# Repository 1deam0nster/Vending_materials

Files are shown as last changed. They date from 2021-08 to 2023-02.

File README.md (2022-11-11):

# !Almavending repo
> Репозиторий для сохранения информации, кода, моделей, и прочего :space_invader:

## 📖 Оглавление

- Структура папок
- Список модулей
- Установка ПО
- Список багов
- Список полезных ссылок
- Релизы
- Лицензия

## 📁 Структура папок

### ПО Вендинг сбер

| Name | Description |
| --- | --- |

| [`Commands`](https://github.com/nhn/tui.editor/tree/master/apps/editor) | Заготовка под Shell script для автоматизации |

### Arduino
Старые версии кода для разных контроллеров и разных машин с разными механиками, надо разобраться, чтот удалить

| Name | Description |
| --- | --- |
| New firmware arduino | [Возможно тут](https://reactjs.org/) будет ссылка на отдельный репозиторий |
| libraries | Папка с библиотеками для компиляции кода |
| Old code | Старые версии кода |
| PlatformIO project | Заготовка прошивки MK под Platformio, не компилируеться из-за новой версии GCC которая указыает на ошибку стандартной библиотеке Servo.h |

### Backup

| Name | Description |
| --- | --- |
| [old.zip | Старые бекапы с большим кол-вом файлов и вложенности(то что не синхронит GIT) + что-то еще |
| [Python_dev_old.zip | Одна их первых версий ПО для Raspberry Pi, простой Flask, роутинг, взаимодействие с MK посредством UART  |
| [Python_dev.zip | Актуальная версия Python app, с мини БД на JSON, интеграция с AQSI, [ссылка](https://github.com/1deam0nster/Python_dev) на отдельный актуальный репозиторий  |
| [`App PAX D200 Sber`](https://github.com/nhn/tui.editor/tree/master/apps/editor) | ПО для терминала Pax D200 для LINUX, ARM |
| [Control Panel Node | Веб приложения на Express Node для управления MK посредством Serial, так и не пригодилось(( |
| [app.py | Старое приложение на Python |
| [app_backup_code | Старое приложение на Python |
| [RPI4_image_alfa | Копия флешки для RPI4 |

### 3D Print Models

| Name | Description |
| --- | --- |
| [Cura | Проекты в куре |
| [Fusion Models | Исходники 3д моделей  |
| [G-Code | Файлы для 3д принтера  |

### Img

Коллекция сохраненок для разных модулей, датчиков, информация по распиновкам. Раздел в процессе наполнения...
<!-- ALL-CONTRIBUTORS-LIST:START - Do not remove or modify this section -->
<!-- prettier-ignore-start -->
<!-- markdownlint-disable -->
<table>
  <tr>
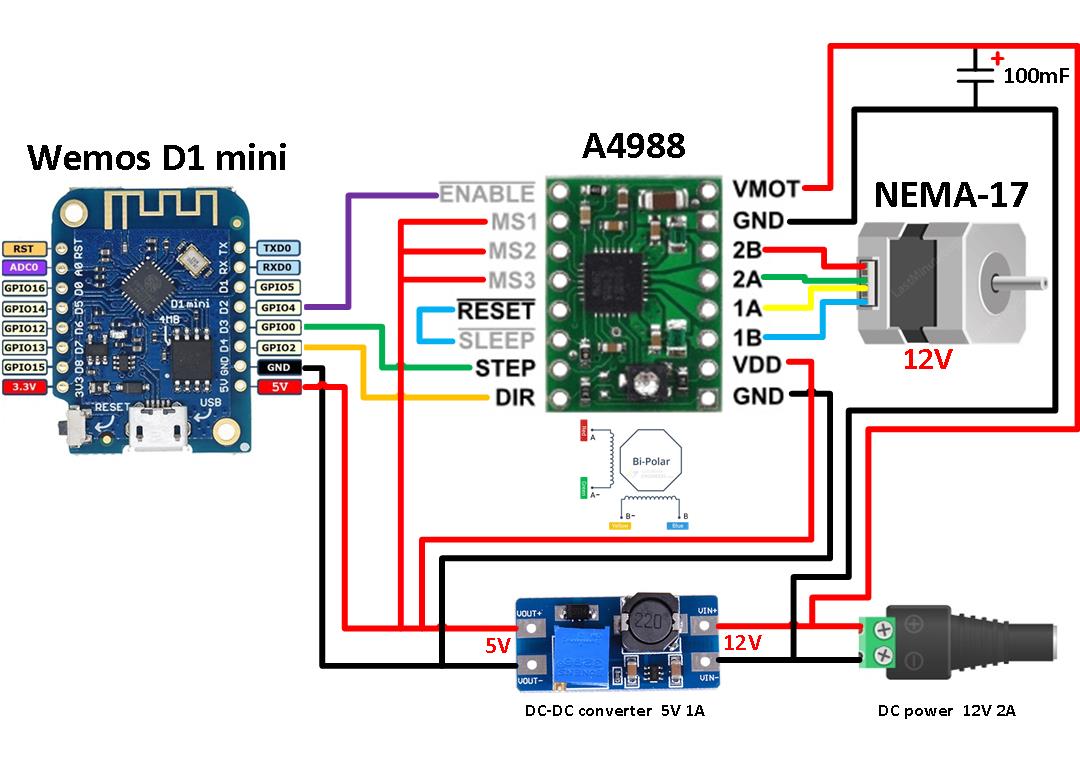
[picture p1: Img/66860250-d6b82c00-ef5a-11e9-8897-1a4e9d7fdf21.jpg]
    <td align="center"></td>
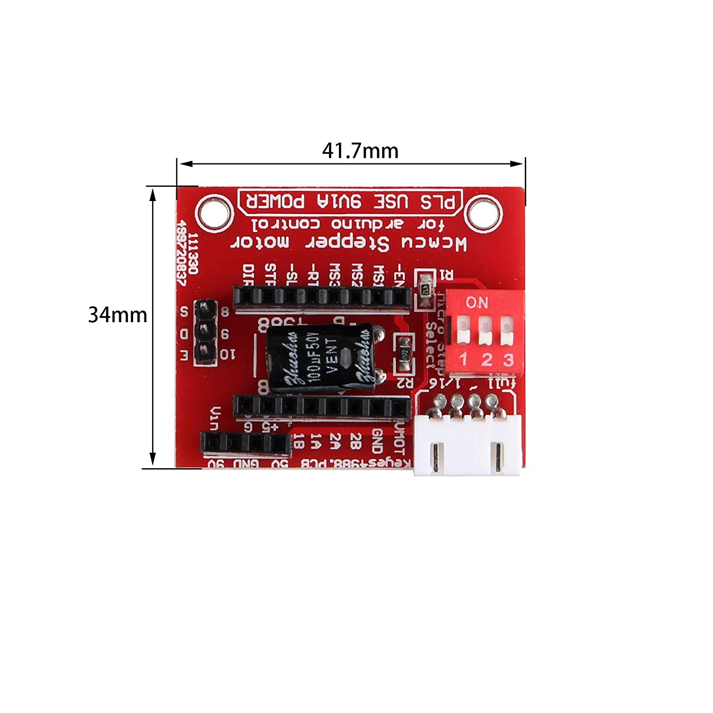
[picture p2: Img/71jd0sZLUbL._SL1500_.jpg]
    <td align="center"></td>
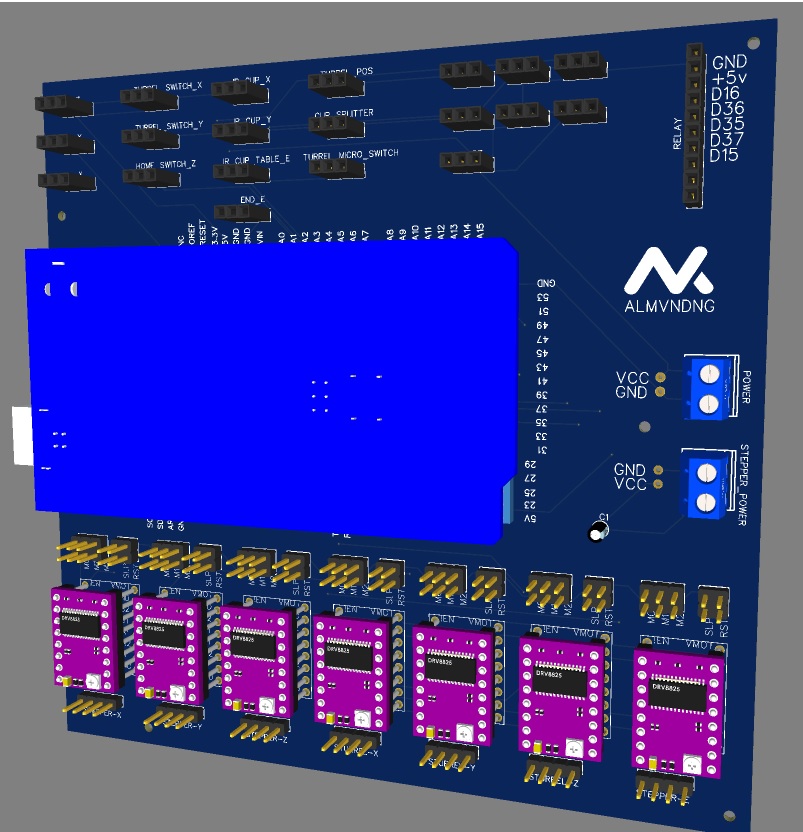
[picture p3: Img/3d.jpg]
    <td align="center"></td>
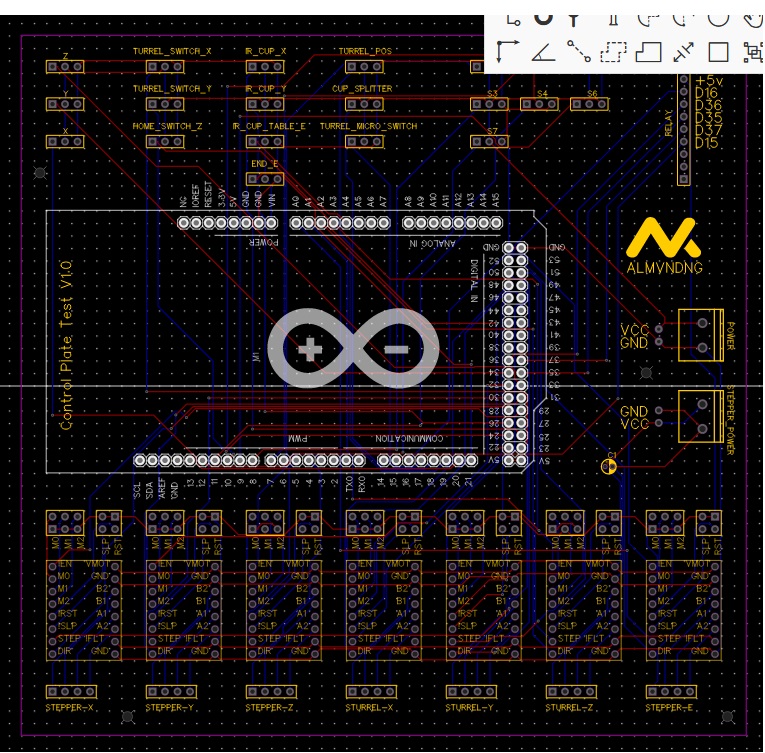
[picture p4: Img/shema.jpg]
    <td align="center"></td>
    <td align="center"></td>
    <td align="center"></td>
    <td align="center"></td>
  </tr>
</table>

<!-- markdownlint-enable -->
<!-- prettier-ignore-end -->
<!-- ALL-CONTRIBUTORS-LIST:END -->

### PCB
Экспорт проекта с ['EasyEDA']:(https://www.easyeda.com) 

##How to recover online project backup：
1、Via folder "online_projects_backup" find out the project as you want
2、Copy to desktop
3、Open the EasyEDA editor, via: Top meun - Open - EasyEDA
4、Select the 'sch' and 'pcb' folder's 'json' files to open, and then save to a new project
5、Saved and finish

### 📃 Python

| Name | Description |
| --- | --- |
| [`evotor`](https://github.com/1deam0nster/Vending_materials/tree/main/Python/Evotor) | Скрипт для отправки фискольных данных в Эвотор |
| [`bot.py`](https://github.com/1deam0nster/Vending_materials/blob/main/Python/bot.py) | Telegram bot для управления машиной |
| [`Aqsi`](https://github.com/1deam0nster/Vending_materials/blob/main/Python/Aqsi) | Aqsi код для фискализации, чека, оплаты |
| [`Python_dev`](https://github.com/1deam0nster/Vending_materials/blob/main/Python/Python_dev) | Основной код для Raspberry PI |

## 🔧 Список модулей на каждую часть

**Турель выдачи стаканчиков**
- Кнопки на input с подтягивающим резистором
- Кнопки на input с подтягивающим резистором
- Кнопки на input с подтягивающим резистором

**Турель с капсулами + кофемашина**
- Магнит для вкл/выкл(Реле)
- Сенсор на землю(Реле) для переключения программы
- Сервопривод
- Сервопривод
- Концевик
- Концевик(в целом резерв)
- Шаговый двигатель(+ драйвер)
- Ir датчик присутствия капсулы
- Механический(оптический) концевик для фиксации завершения приготовления 

**Выдача сливок**
- Шаговый двигатель(+ драйвер)
- Сервопривод
- Сервопривод
- Концевик
- Ir датчик присутствия капсулы

**Выдача сахара**
- Один сервопривод
- Ir датчик присутствия 

**Выдача шоколада**
- Сервопривод
- Ir датчик присутствия 

**Окно**
- Шаговый двигатель
- Концевик
- Датчик расстояния (тот желтый цилиндр, чтобы понять, что стакан забрали)
- Сервопривод (резерв)

**Манипулятор для подачи стакана**
- Шаговый двигатель
- Концевик
- Датчик ИК
- Сервопривод
- Сервопривод

## Установка ПО

Описание в процессе...

```sh
$ git clone https://github.com/{your-personal-repo}/tui.editor.git
$ npm install
$ npm run build toastmark
$ npm run test editor
```
## 🐛Список багов
- [ ] ...

### Примерный список задач

```
### Общие задачи
- [x] Собрать тестовый стенд для кофемашины
- [x] Разработка ПО для микроконтроллера(для тестового стенда), выполнение полного цикла приготовления кофе на тестовом стенде в ручную с компа посредством ручного ввода 
- [x] Разработка Flask приложения(для тестового стенда), выполнение полного цикла приготовления кофе, оплаты, загрузки, ребута, частично реализовать систему обслуживания
- [ ] Разработка платы PCB
- [ ] Собрать полную статистику сколько и каких всего материалов использованно для создания одной кофе машины, создать тут раздел
- [x] Админ панель(обслуживание) или может пока обойтись кнопкой
- [ ] Выход в сеть, легкий удаленный доступ, объединение в одну сеть(хз проще всего наверное VPN)

### Разработка Flask приложения 
- [x] Создание мини БД для учета(почти готово, надо сделать сохранение после перезапуска)
- [x] Роутинг страниц
- [x] Шаблоны для отображения(черновые, пока без дизайна)
- [x] Подумать как будет храниться информация в БД, пока это только объект внутри программы, возможно можно сделать тупо хранение на флешке файлов JSON
- [x] Код для передачи g-code комманд MK 
- [x] Дизайн всех страниц, сверстать, сделать шаблоны 
- [x] Отрефакторить предыдущие наработки, чтоб все было модульно и круто
- [x] Добавить описание как это все запускать, добавить описание к ['репозиторию']:(https://github.com/1deam0nster/Python_dev) Python_dev
- [x] Создать админ панель(обслуживание автомата для начала), отображение статистики продаж

### Разработка ПО для микроконтроллера
- [x] Прописать тестовые команды для отладки
- [ ] Продумать сколько команд нужно для приготовления кофе, разделить их на маленькие части для переиспользования кода, собрать основные команды 
- [X] Обратная связь с Raspberry PI
- [ ] Инициализация eeprom памяти для экстренных ситуаций(когда свет потух, знать местоположение турели, например)
- [ ] Режим обслуживания, сброс кол-ва капсул в ПЗУ(eeprom)
- [ ] Создать репозиторий для кода МК, а то заебало плодить кучу версий 

## Список не глобальных задач
- [x] Создать описание к данному репозиторию
- [ ] отрефакторить размещение и нэйминг
- [ ] Добавить ссылки на остальные репозитории в данный README
- [ ] Добавить папку 3d, разделить её на настройки принтера, 3д модели(Fusion360), g-code
- [ ] Добавить раздел список оборудования и конструкционных материалов(наполнить по окончанию стройки машины, если это возможно)
- [ ] Добавить к списку модулей таблицу с пинами для подключения
- [ ] Собрать все медия материалы для истории
```

## Список полезных ссылок
['Модель дисплея']:(https://www.waveshare.com/product/raspberry-pi/displays/lcd-oled/13.3inch-hdmi-lcd-h.htm)

## Список релизов

* 0.2.1
    * CHANGE: Update docs (module code remains unchanged)
* 0.2.0
    * CHANGE: Remove `setDefaultXYZ()`
    * ADD: Add `init()`
* 0.1.1
    * FIX: Crash when calling `baz()` (Thanks @GenerousContributorName!)
* 0.1.0
    * The first proper release
    * CHANGE: Rename `foo()` to `bar()`
* 0.0.1
    * Work in progress

## 📜 License

Закрытый проект и репозиторий идите все [нахуй](https://нахуй.ру) © [ReutaDmitry](https://reutadmitry.com).

[(Back to top)](##Оглавление)

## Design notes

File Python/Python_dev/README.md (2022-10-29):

# Python_dev
Скрипт представляет из себя простое WSGi-приложение на Flask, SQLlite, WTForms, Jinja  и Serial. Сервер постоянно находится в режиме ожидания очередного запроса и как только он приходит, формирует ответ клиенту, в виде HTML-документа. Этот документ возвращается в браузер и пользователь видит на экране устройства страницу. 

Rак только фреймворк запущен, у нас активизируется локальный веб-сервер и мы можем в браузере создавать запрос, используя начальный адрес:
http://127.0.0.1:5000/ 

## Установка зависимостей
```
pip install Flask 

```

# AQSI app module
run script:
```
python aqsi.py --amount (transaction ammount)
```

example:
```
python aqsi.py --amount 150
```

## Flask app

Running on http://127.0.0.1:5000

run script:

```
python main.py
```

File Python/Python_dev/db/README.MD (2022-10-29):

# База дынных
### Действия с БД
Создание таблицы из консоли Python
```
py
from db.db import create_db
create_db()
```

Создание таблицы c помощью файла Python
```
python create.py
```

Удаление таблицы c помощью файла Python
```
python delete.py
```

### Описание табличных данных
| Название ячейки | Тип данных | Описание |
| --- | --- | --- |
| id |  INTEGER | Уникальное значение id |
| name | TEXT | Название кофе |
| descriptions | TEXT | Описание |
| short_description | TEXT | Короткое описание |
| value | INTEGER | Кол-во капсул |
| g-code | TEXT | Код для МК |
| img_url | TEXT | Ссылка на изображение |
| link_url | TEXT | Ссылка на страницу покупки |

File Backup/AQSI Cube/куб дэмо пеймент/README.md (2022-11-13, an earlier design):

## demo-cube-payment

Приложение, позволяющее протестировать socket интерфейс vend'а в POS режиме.

в `/mnt/data/aqsi-config.json` должны быть следующие параметры:

```
{
  "MainMode": 3,
  "PosMode" 1
}
```

Происходит подключение к vend на порту 4455 и отправляется json с командой по протоколу (документ в папке doc). Данные берутся из левого текстового поля.

Vend получает команду и преобразует ее в xml, передает в papp, тот в свою очередь дополянет xml своими данными и отправляет в jpay. Потом та же цепочка в обратную сторону, в итоге ответ от vend в виде json отобразится в правом текстовом поле.

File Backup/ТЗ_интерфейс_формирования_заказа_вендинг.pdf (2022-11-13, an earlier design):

# Интерфейсы формирования заказа

# Для кофе-вендинга

# Параметры дисплея

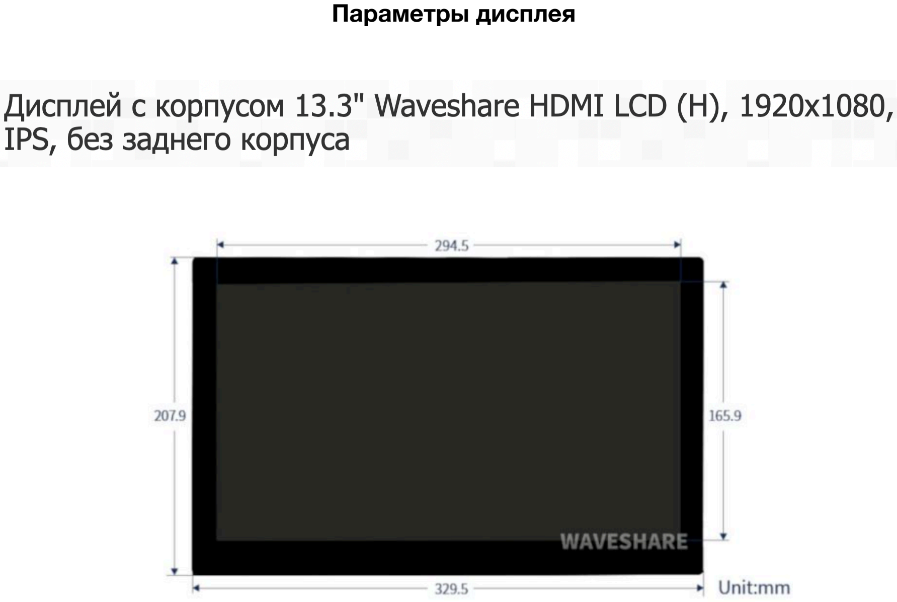
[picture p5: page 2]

# Задачи по функционалу

| Задача | Комментарий | Свойства
1 Выбор позиции (сорта) кофе | | Отображение до 10 позиций для выбора. Учесть вид (способ) отображения, в случае полной продажи каких то позиций | Для каждой позиции загрузка (редактирование) и отображение: Изображение; описание; стоимость (отдельные поля)
2 Выбор объема порции | | Отображение 2х вариантов приготовления для выбранной позиции: из одной капсулы или из двух | Выбор влияет на отображение конечной стоимости заказа
3 Выбор количества порций | сливок | Возможность выбора: 0; 1 или 2 порции Учесть случай, если позиция распродана | Отображение и возможность редактирования (загрузки): изображения; описания; стоимости Выбор влияет на отображение конечной стоимости заказа
4 Выбор количества порций | сахара | Возможность выбора: 0; 1 или 2 порции Учесть случай, если позиция распродана | Отображение и возможность редактирования (загрузки): изображения; описания; стоимости Выбор влияет на отображение конечной стоимости заказа
5 Выбор количества порций | шоколадок | Возможность выбора: 0; 1 или 2 порции Учесть случай, если позиция распродана | Отображение и возможность редактирования (загрузки): изображения; описания; стоимости Выбор влияет на отображение конечной стоимости заказа
6 Отображение итогового | заказа и конечной стоимости | | Стоимость будет автоматически загружаться в поле, на основании выбранных для заказа позиций

| Экран | Комментарий | Свойства
1 В режиме ожидания | | На экране транслируется видеоролик Поверх изображения заметная кнопка «Сделать заказ» | После нажатия кнопки открывается экран формирования заказа
2 Формирование заказа | | Экран может быть быть представлен как одним окном, так и двумя последовательными. Например, сначала выбор сорта, а после выбора открывается окно с возможностью выбора дополнительных позиций | В случае неактивности через какое то время автоматически экран переходит в режим ожидания
3 Экран оплаты | | После подтверждения заказа отображается экран с инструкцией по оплате в терминале рядом с дисплеем | Отображение итогового заказа, суммы к оплате и инструкции по оплате. Обязательно отображение кнопки «Назад» для возврата к экрану «Формирования заказа»
4 Экран ожидания | приготовления | Надо что то придумать. Возможно отображение какого то видеоролика, картинок или текста. Можно отобразить статус приготовления в процентах. | Выход из текущего экрана происходит только по команде от компьютера автомата
5 Экран ошибки | | Отображение информации о фиксации неисправности с указанием инструкции для связи с оператором | Выход из текущего экрана происходит только по команде от компьютера автомата

# Дополнительные экраны

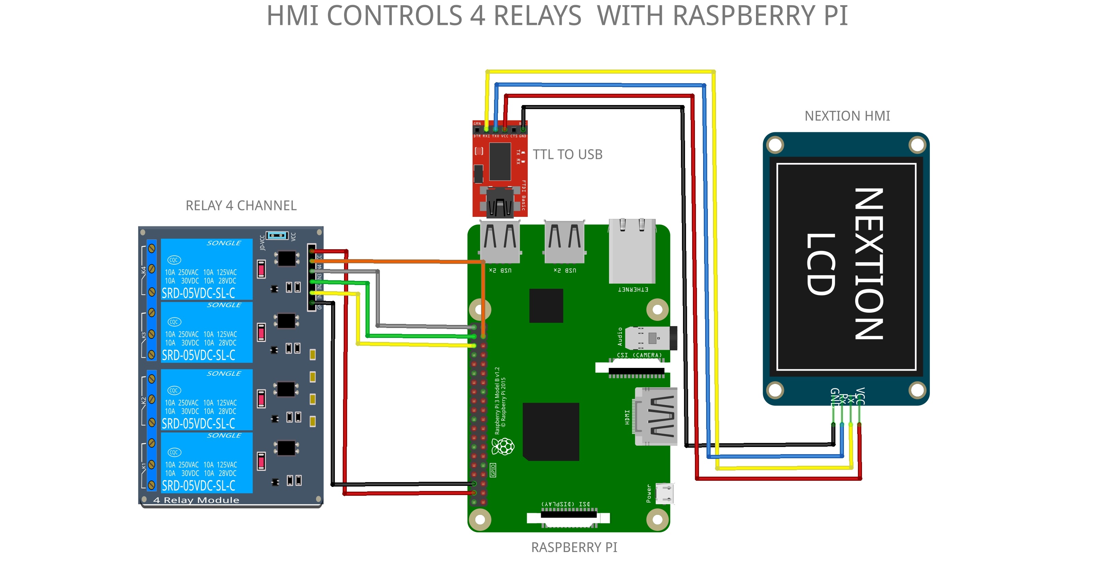
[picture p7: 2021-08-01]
Python/Stuff/4Relays_Raspi_HMI/HMI_Relays_Raspi_bb.jpg

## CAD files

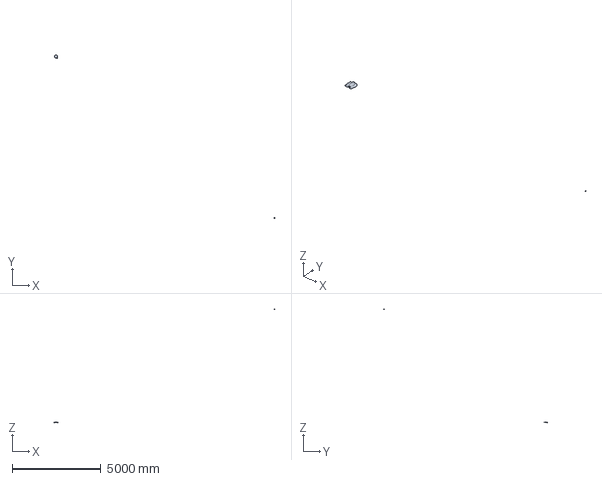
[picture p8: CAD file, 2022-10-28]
3D Print models/Cura/Print projects/CE3_Основа приема капсул.3mf
12387.3 x 9195.8 x 6390.0 mm

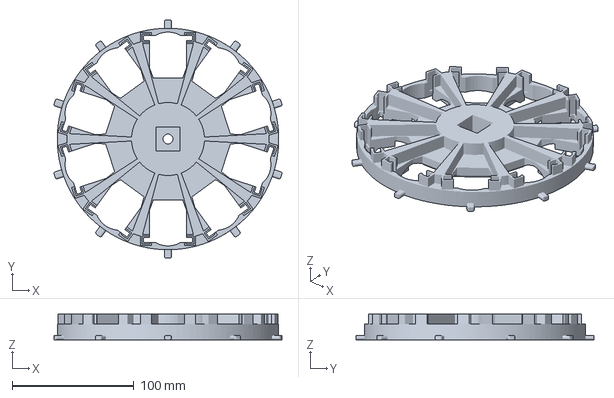
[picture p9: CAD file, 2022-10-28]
3D Print models/Cura/Print projects/CE3_Нижняя турель капсул.3mf
187.4 x 195.9 x 21.0 mm

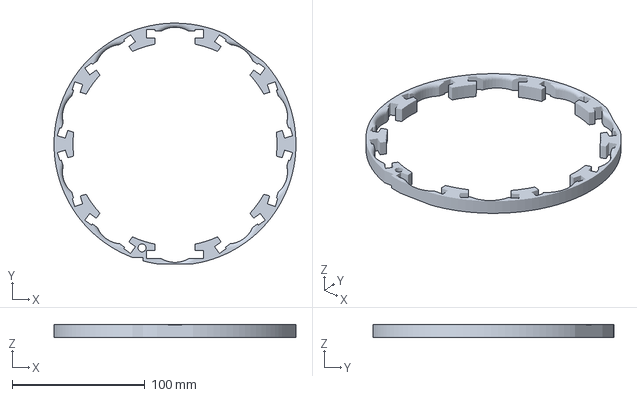
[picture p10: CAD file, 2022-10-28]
3D Print models/Cura/Print projects/CE3_Держатель профиля.3mf
182.0 x 181.0 x 10.0 mm

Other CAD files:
3D Print models/Fusion Models/16.10_mekhanizm_kapsuli_v2.0.f3d
3D Print models/Fusion Models/21.10_kapsul.f3d
3D Print models/Fusion Models/25.10_osnova.f3d
3D Print models/Fusion Models/27.10_14.40_kapsuli.f3d
3D Print models/Fusion Models/27.10_Derzhatel_motor_turel.f3d
3D Print models/Fusion Models/27.10_only_turel_cap.f3d
3D Print models/Fusion Models/28.10_Derzhatel_motor_turel.f3d
3D Print models/Fusion Models/mekhanizm_kapsuli_14.10_V2.f3d
3D Print models/Fusion Models/osnova_11.10_win.f3d

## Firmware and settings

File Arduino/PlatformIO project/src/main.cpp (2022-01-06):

#include <Arduino.h>
#include "A4988.h"
#include "MultiDriver.h"
#include "SyncDriver.h"
#include "BasicStepperDriver.h"
#include <Servo.h>
#include <gcode.h>


//------Переменная для ШД сахара
int milk_stepper_1 = 0;
int milk_stepper_2 = 0;
int milk_stepper_3 = 0;

//------Переменные для IR датчиков турели------
bool check_1 = false;
bool check_2 = false;
bool check_3 = false;
bool check_4 = false;
bool check_5 = false;
bool val = false;

//------Подключение серв------
Servo servo;
Servo servo_r; 
Servo servo_sug;

//------Подключение концевиков------
#define stop_x 20
#define stop_y 34
#define stop_z 33

#define home_switch_z 22 // концевик для Z
#define home_switch_e 21 //концевик для E

#define turrel_switch_x 23 //концевик турелли с капсулами Х
#define turrel_switch_y 24 //концевик турелли с капсулами Y

#define ir_cap_y 26 //концевик капсулы Y
#define ir_cap_x 25 //концевик капсулы X 27

bool cup_table; 
#define ir_cup A4

//-----Реле на кофемашину-----
#define OPEN 37
#define START_COFE 35
#define CLOSE 36

//-----Для выдачи стаканчиков -----
#define RELAY_CUP 16
#define RELAY_TURREL 15

const int turrel_pos = 19;     // номер входа, подключенный к кнопке Turret position
const int turrel_micro_switch = 17;     // номер входа, подключенный к кнопке Turret micro switch
const int cup_splitter = 18;     // номер входа, подключенный к кнопке Cup splitter
int motor_val = 3;

//------Подключение ШД------
// Motor steps per revolution. Most steppers are 200 steps or 1.8 degrees/step
#define MOTOR_STEPS 200
//Number of steps to take 1 millimeter
#define STEPS_MM 80
// Target RPM for X axis motor
#define MOTOR_X_RPM 30
#define MOTOR_Y_RPM 30
#define MOTOR_Z_RPM 120
#define MOTOR_E_RPM 120
#define MOTOR_M0_RPM 120
#define MOTOR_M1_RPM 120
#define MOTOR_M2_RPM 120
#define NAV_MOTOR_X_RPM 120
#define NAV_MOTOR_Y_RPM 120
#define NAV_MOTOR_Z_RPM 120

// X motor
#define DIR_X 47
#define STEP_X 48
#define ENA_X 46

// Y motor
#define DIR_Y 50
#define STEP_Y 51
#define ENA_Y 49

// Z motor
#define DIR_Z A2
#define STEP_Z A3
#define ENA_Z A1

// //// E0 motor
// #define DIR_E 53
// #define STEP_E A0
// #define ENA_E 52

// ///из первой ардуины
// // X motor
// #define NAV_DIR_X 28
// #define NAV_STEP_X 27
// #define NAV_ENA_X 29

// // Y motor
// #define NAV_DIR_Y 31
// #define NAV_STEP_Y 30
// #define NAV_ENA_Y 32

// // Z motor
// #define NAV_DIR_Z 4
// #define NAV_STEP_Z 5
// #define NAV_ENA_Z 3

// // M0 motor
// #define DIR_M0 39
// #define STEP_M0 38
// #define ENA_M0 40

// // M1 motor
// #define DIR_M1 A6
// #define STEP_M1 A5
// #define ENA_M1 A7

// // M2 motor
// #define DIR_M2 A9
// #define STEP_M2 A8
// #define ENA_M2 A1

// If microstepping is set externally, make sure this matches the selected mode
// 1=full step, 2=half step, 4 = 1/4, 8 = 1/8 and 16 = 1/6 Microsteps.
#define MICROSTEPS 8

// 2-wire basic config, microstepping is hardwired on the driver
// Other drivers can be mixed and matched but must be configured individually
 #include "DRV8825.h"
// #define MODE0 10
// #define MODE1 11
// #define MODE2 12
// DRV8825 stepper(MOTOR_STEPS, DIR, STEP, SLEEP, MODE0, MODE1, MODE2);


//MultiDriver controller(turel_X, turel_Y, turel_Z);

BasicStepperDriver nav_X(MOTOR_STEPS, DIR_X, STEP_X);O
BasicStepperDriver nav_Y(MOTOR_STEPS, DIR_Y, STEP_Y);
BasicStepperDriver nav_Z(MOTOR_STEPS, DIR_Z, STEP_Z);
MultiDriver controller(nav_X, nav_Y, nav_Z);
//MultiDriver controller2(stepperE);

//------Настройка команд------
//#define NUMCOMMANDS 10
void homing();
void moviment();
void gotoLocation();
void servofn();
void rotate_tower();
void rotate_tower2();
void check_servo_x();
void dropcap_x();
void check_servo_y();
void dropcap_y();
void rotate_cup_back();
void rotate_cup_to();
void stepper_e0();
void stepper_e1();
void relay();
void turrelFunction();
void cup();
void cup_fn();
void check_turrelfn();
void check_turrelfn2();
void open_cofe();
void close_cofe();
void start_cofe();
void servo_sugar();
void milk_stepper_cmd();
void milk_stepper_reset_cmd();

//------для объединения комманд
void command_x();
void command_x_a();
void command_x_b();
void command_x_a_b();
void command_y();
void command_y_a();
void command_y_b();
void command_y_a_b();
void get_cap_x();
void get_cap_y();
void loud_cap();
void get_cupple();
void to_client();
void test();
void table();
void m0();
void m6();
void m7();

double X;
double Y;
double Z;
double D;
double N;
double T;

commandscallback commands[35] = {
{"X1", command_x}, {"X2", command_x_a}, {"X3", command_x_b}, {"X4", command_x_a_b},
{"Y1", command_y}, {"Y2", command_y_a}, {"Y3", command_y_b}, {"Y4", command_y_a_b},
{"B1", get_cap_x}, {"B2", get_cap_y}, {"B3", loud_cap}, {"B4", get_cupple}, {"B5", to_client}, {"B6", test}, {"T3", table}, {"M4", milk_stepper_cmd}, {"M5", milk_stepper_reset_cmd}, {"M6", m6}, {"M7", m7},
{"M1", open_cofe}, {"M2", close_cofe}, {"M3", start_cofe}, {"G1", homing}, {"G0", moviment}, {"S0", servofn}, {"S3", servo_sugar},
{"T1", rotate_tower}, {"T2", rotate_tower2}, {"C1", dropcap_x}, {"C2", dropcap_y}, {"S1", rotate_cup_to}, {"S2", rotate_cup_back}, 
{"E0", stepper_e0}, {"E1", stepper_e1}, {"C0", cup}
};
gcode Commands(35, commands);


void setup() {
//  tmr.setPeriodMode();
    //------Pins для концевиков-------
  pinMode(stop_x, INPUT_PULLUP);
  pinMode(stop_y, INPUT_PULLUP);
  pinMode(stop_z, INPUT_PULLUP);

  pinMode(home_switch_z, INPUT_PULLUP);
  pinMode(home_switch_e, INPUT_PULLUP);
  
  pinMode(ir_cap_x, INPUT_PULLUP);
  pinMode(ir_cap_y, INPUT_PULLUP);

  pinMode(ir_cup, INPUT_PULLUP);
  //------Pins для реле-------
//  pinMode(r1, OUTPUT);
//  digitalWrite(r1, HIGH);
//  pinMode(r2, OUTPUT);
//  digitalWrite(r2, HIGH);
//  pinMode(r3, OUTPUT);
//  digitalWrite(r3, HIGH);
//  pinMode(r4, OUTPUT);
//  digitalWrite(r4, HIGH);
//  pinMode(r5, OUTPUT);
//  digitalWrite(r5, HIGH);
//  pinMode(r6, OUTPUT);
//  digitalWrite(r6, HIGH);
//  pinMode(r7, OUTPUT);
//  digitalWrite(r7, HIGH);
//  pinMode(r8, OUTPUT);
//  digitalWrite(r8, HIGH);
  pinMode(OPEN, OUTPUT);
  digitalWrite(OPEN, HIGH);
  pinMode(START_COFE, OUTPUT);
  digitalWrite(START_COFE, HIGH);
  pinMode(CLOSE, OUTPUT);
  digitalWrite(CLOSE, HIGH);
  
  //------Для стаканчиков-----
  pinMode(turrel_pos, INPUT);
  pinMode(turrel_micro_switch, INPUT);
  pinMode(cup_splitter, INPUT_PULLUP);
  pinMode(RELAY_CUP, OUTPUT);
  pinMode(RELAY_TURREL, OUTPUT);
  digitalWrite(RELAY_CUP, HIGH);
  digitalWrite(RELAY_TURREL, HIGH);
  
  //  SerialUSB.begin(115200);
  Serial.begin(9600);

  nav_X.begin(NAV_MOTOR_X_RPM, MICROSTEPS);
  nav_Y.begin(NAV_MOTOR_Y_RPM, MICROSTEPS);
  nav_Z.begin(NAV_MOTOR_Z_RPM, MICROSTEPS);
  
  // if using enable/disable on ENABLE pin (active LOW) instead of SLEEP uncomment next two lines
  // turel_X.setEnableActiveState(LOW);
  // turel_Y.setEnableActiveState(LOW);
  // turel_Z.setEnableActiveState(LOW);
  // stepper_E.setEnableActiveState(LOW);
  // stepper_M0.setEnableActiveState(LOW);
  // stepper_M1.setEnableActiveState(LOW);
  // stepper_M2.setEnableActiveState(LOW);
  nav_X.setEnableActiveState(LOW);
  nav_Y.setEnableActiveState(LOW);
  nav_Z.setEnableActiveState(LOW);

//  check_servo_x();
//  check_servo_y();

    //----Читаем значения переменных с сахаром и сливками
//  EEPROM.get(0, milk_stepper_1);
//  EEPROM.get(1, milk_stepper_2);
//  EEPROM.get(2, milk_stepper_3);
}

void loop() {
   Commands.available();

  //----------------------------------------------------------------------------------
  //   Крутим турель если нету стаканчика
  //----------------------------------------------------------------------------------
  turrelFunction();

}

// #include "turell_cup.h"
// #include "cup.h"
// #include "homing.h"
// #include "relay.h"
// #include "servo.h"
// #include "turel_x.h"
// #include "turel_y.h"
// #include "move.h"
// #include "rotate.h"
// #include "steppers.h"
#include "custom.h"
// #include "cream.h"

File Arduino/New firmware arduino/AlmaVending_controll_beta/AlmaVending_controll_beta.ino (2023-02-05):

// НАСТРОЙКИ
#define INIT_KEY 0     // ключ первого запуска. 0-254, на выбор eeprom position

// раздефайнить или задефайнить для использования
#define DEBUG_ENABLE
#ifdef DEBUG_ENABLE
#define DEBUG(x) Serial.println(x)
#else
#define DEBUG(x)
#endif

// ---- Турель загрузки капсул ---
#define turrel_cap_homing 15 // -----Удалить
#define turrel_zero_homing 52 //Определения нулевой точки турели
#define ir_cap 53 //Проверка наличия капсулы
#define turrel_cap_servo 2 //Выдача капсулы
#define turrel_cap_servo_mini 5 //Задвижка очереди
#define directionPin 47 // direction_ct
#define stepPin 46 // step_ct
#define turrelEnablePin 48

// ---- Кофе машина ---
#define cofe_machine_ir 24 //end of prog
#define coffe_machine_start_pin 51 //magnit pin 22
#define cofe_machine_check_button_pin 50 //sensor button 51

// ---- Турель для выдачи сливок ---
#define dir_sc 44
#define step_sc 45
#define cream_servo 9 //или 10
#define cream_homing 12 // концевик турели 12
#define ir_cream 11 // датчик препятствия 11 
int cream_turrel_number = 1;

// ---- Манипулятор ---
#define step_manipul 37
#define dir_manipul 43
#define servo_manipul 3

// ---- Команды ---
#define NUMCOMMANDS 27

//-----Для выдачи стаканчиков -----
#define RELAY_CUP 22
#define RELAY_TURREL 25
#define turrel_pos 19     // номер входа, подключенный к кнопке Turret position
#define turrel_micro_switch 38     // номер входа, подключенный к кнопке Turret micro switch
#define cup_splitter 18     // номер входа, подключенный к кнопке Cup splitter
int motor_val = 3;

//-----Сахар -----
#define sugar_servo 4
#define sugar_ir_control 49

//-----Шоколад -----
#define choco_servo 8
#define choco_ir_control 36

// БИБЛИОТЕКИ
#include <gcode.h>
#include <AccelStepper.h>
#include <Servo.h>
#include <EEPROM.h>


// МАКРОФУНКЦИИ
// печать в серийный порт, кастом функция
#define printWords()   \
  Serial.print("OK");

// данный код будет выполняться каждые 100 мс
#define EVERY_MS(x) \
  static uint32_t tmr;\
  bool flag = millis() - tmr >= (x);\
  if (flag) tmr += (x);\
  if (flag)

#define GET_DATA EEPROM.read(0)
#define SET_DATA(x) EEPROM.write(0, (x))
#define GET_CREAM_POS_NUM EEPROM.read(1)
#define SET_CREAM_POS_NUM(x) EEPROM.write(1, (x))


//ПЕРЕМЕННЫЕ
//---Глобальные переменные---
int big_pos_cap = 0;
int mini_pos_cap = 0;


int pos_cap = 0; //удалить
int pos_key = 180;
int turrelCurrentPosition;
//bool calibrating = false;

int cream_check_value = 0;
int cap_check_value = 0;
bool machine_sensor;

//---turrel---
void go_to_pos();
void go_number_turrel();
void zero_homing_turrel();
void get_position();
//void correct_pos();

//---turrel_cream---
void go_to_pos_cream();
void go_number_turrel_cream();
void zero_homing_turrel_cream();
void get_position_cream();
void cream_drop();
void cream_check();
void cream_servo_test();

//---cup turrel---
void turrelFunction();
void cap_check();

//---relay, servo---
void servofn();
void relayfn();

//---commands---
void drop_cap();
void check_machine();
void start_coffe();
void start_coffe_machine();
void sugar_command();
void chocolate_command();
void cup_fn();
void choco_check();
void cream_check();
void sugar_check();
void cream_restart_eeprom_position();

//---manipulaator---
void go_to_pos_man();
void go_man_stepper();
void up_man();
void servo_man();
//void get_position();
void to_win_man();
void to_machine_man();

//---commands variable---
double N;
double D;
double A;
double S;
double I;
double T;
double B;

//---commands array---
commandscallback commands[NUMCOMMANDS] = {
  {"G0", start_coffe_machine},
  {"C0", drop_cap}, {"C1", check_machine}, {"C2", start_coffe}, {"C3", cup_fn}, {"C4", choco_check}, {"C5", sugar_check},
  {"P0", sugar_command}, {"P1", chocolate_command},
  {"T0", go_to_pos}, {"T1", go_number_turrel}, {"T2", zero_homing_turrel}, {"T3", get_position},
  {"M0", go_to_pos_cream}, {"M1", go_number_turrel_cream}, {"M2", zero_homing_turrel_cream}, {"M3", get_position_cream}, {"M4", cream_drop}, {"M5", cream_restart_eeprom_position}, {"M6", cream_servo_test},
  {"F0", go_to_pos_man}, {"F1", up_man}, {"F2", servo_man}, {"F3", to_win_man}, {"F3", to_machine_man},
  {"S0", servofn}, {"R0", relayfn},
};

//ОБЬЕКТЫ
AccelStepper turrel(1, stepPin, directionPin); // pin 3 = step, pin 6 = direction
AccelStepper manipul(1, step_manipul, dir_manipul); // pin 3 = step, pin 6 = direction
AccelStepper cream(1, step_sc, dir_sc); // pin 3 = step, pin 6 = direction

Servo cap_drop;
Servo myservo;
Servo sugar;
Servo chocolate;
Servo manipulator;
//Servo cream;
gcode Commands(NUMCOMMANDS, commands);


void setup()
{


  turrel.setEnablePin(48);
  turrel.setMaxSpeed(1000);
  turrel.setSpeed(600);
  turrel.setAcceleration(500);
  turrel.setEnablePin(turrelEnablePin);
  turrel.enableOutputs();
  
  pinMode(turrel_cap_homing, INPUT_PULLUP);
  pinMode(ir_cap, INPUT_PULLUP);
  
  //------Проверка остатка сахара и шоколада-----
  pinMode(sugar_ir_control, INPUT_PULLUP);
  pinMode(choco_ir_control, INPUT_PULLUP);
  pinMode(cofe_machine_ir, INPUT_PULLUP);
  pinMode(ir_cream, INPUT_PULLUP);
  
  //------Для стаканчиков-----
  pinMode(turrel_pos, INPUT_PULLUP);
  pinMode(turrel_micro_switch, INPUT_PULLUP);
  pinMode(cup_splitter, INPUT_PULLUP);
  pinMode(RELAY_CUP, OUTPUT);
  pinMode(RELAY_TURREL, OUTPUT);
  digitalWrite(RELAY_CUP, HIGH);
  digitalWrite(RELAY_TURREL, HIGH);

//  turrel_drop.attach(turrel_cap_servo);
  cap_drop.attach(turrel_cap_servo);
  cap_drop.writeMicroseconds(1800);

  manipulator.attach(servo_manipul);
  
//  #ifdef DEBUG_ENABLE
    Serial.begin(9600);
//  #endif

//  Serial.println(GET_DATA);
  
  
}

void loop() {
  for (;;) {
    // ваш код
    Commands.available();
    turrelFunction();
//    DEBUG(digitalRead(ir_cream)); // 0 - есть капсула, 1 - нету
//    DEBUG(digitalRead(cofe_machine_sensor));
//    DEBUG(digitalRead(sugar_ir_control));
//    DEBUG(digitalRead(choco_ir_control));
//    DEBUG(digitalRead(turrel_micro_switch));
//    DEBUG(digitalRead(turrel_pos));
//    DEBUG(digitalRead(cup_splitter));
//    DEBUG(digitalRead(cream_homing));
 }
}
#include "turrel_cream.h"
#include "turrel.h"
#include "commands.h"
#include "general_commands.h"
#include "servo.h"
#include "relay.h"
#include "manipulator.h"

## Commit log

2021-05-31 add panels
    add relay, g-code buttons, 2nd relay
2021-08-30 Add structure
    [HMI_Relays_Raspi.fzz]
2021-08-31 Update
    Add sketch, split arduinos
2021-09-03 add sugar
    add sugar command and cofe timer
2021-09-09 Updates
    add steppers fom m4 cream command, update sugar servo command
2022-01-03 Add pin io img, vend soft
2022-01-03 add libs
    add libraries for arduino
2022-01-04 fix test code
    fixing test code for arduino DUE
2022-02-06 Add PCB file
2022-10-28 Refactoring folders and content
    Add 3d print models, Refactoring structure of folder
    [16.10_mekhanizm_kapsuli_v2.0.f3d, 21.10_kapsul.f3d, 25.10_osnova.f3d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]
2022-10-30 add futures raspberry
    add admin futures edit, delete items in db
2022-11-02 Add futures arduino firmware
    add accel stepper library, add turrel points, minimal all commands add
2022-11-02 Python_dev updates
    add img edit in admin panel, fix tables size
    [app.py]
2022-11-03 add some futures
    add item template(send g-code, check request) add admin fixes css,
    [app.py, turrel.h]
2022-11-11 adit arduino firmware
    correcting servo cap drop
    [commands.h, commands.py]
2022-11-13 Add some documentation to AQSI Cube
    Dock for AQSI, test app for requests
    [27.10_Derzhatel_motor_turel.f3d, 28.10_Derzhatel_motor_turel.f3d]
2022-12-07 add fixes adn hacks
    [AlmaVending_controll_beta.ino, app.py, commands.h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]
2023-02-05 Update arduino code add manipulator
